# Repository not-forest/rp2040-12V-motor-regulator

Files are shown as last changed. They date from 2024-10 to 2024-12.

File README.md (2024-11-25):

# RP2040-Zero Powered 12V Motor Controller

RP2040 microcontroller handles status LEDs, an H-Bridge driver, and a rotary encoder input. RP2040's **PIO** is used to read encoder signals as a state machine, completely restraining bouncing errors from the input lines. This allows to use cheap encoders and have an amazing precision.

---

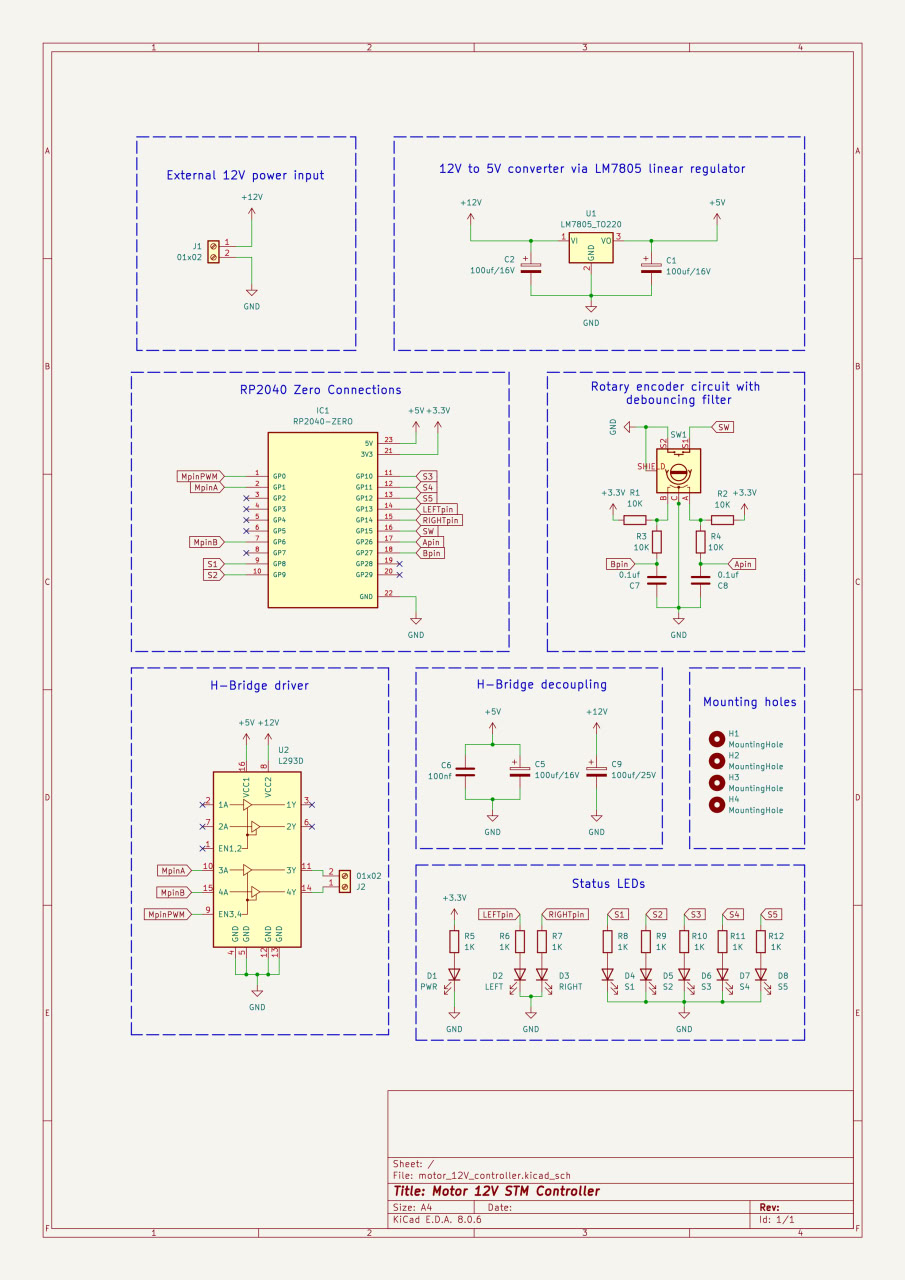
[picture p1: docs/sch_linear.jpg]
Schematic Linear

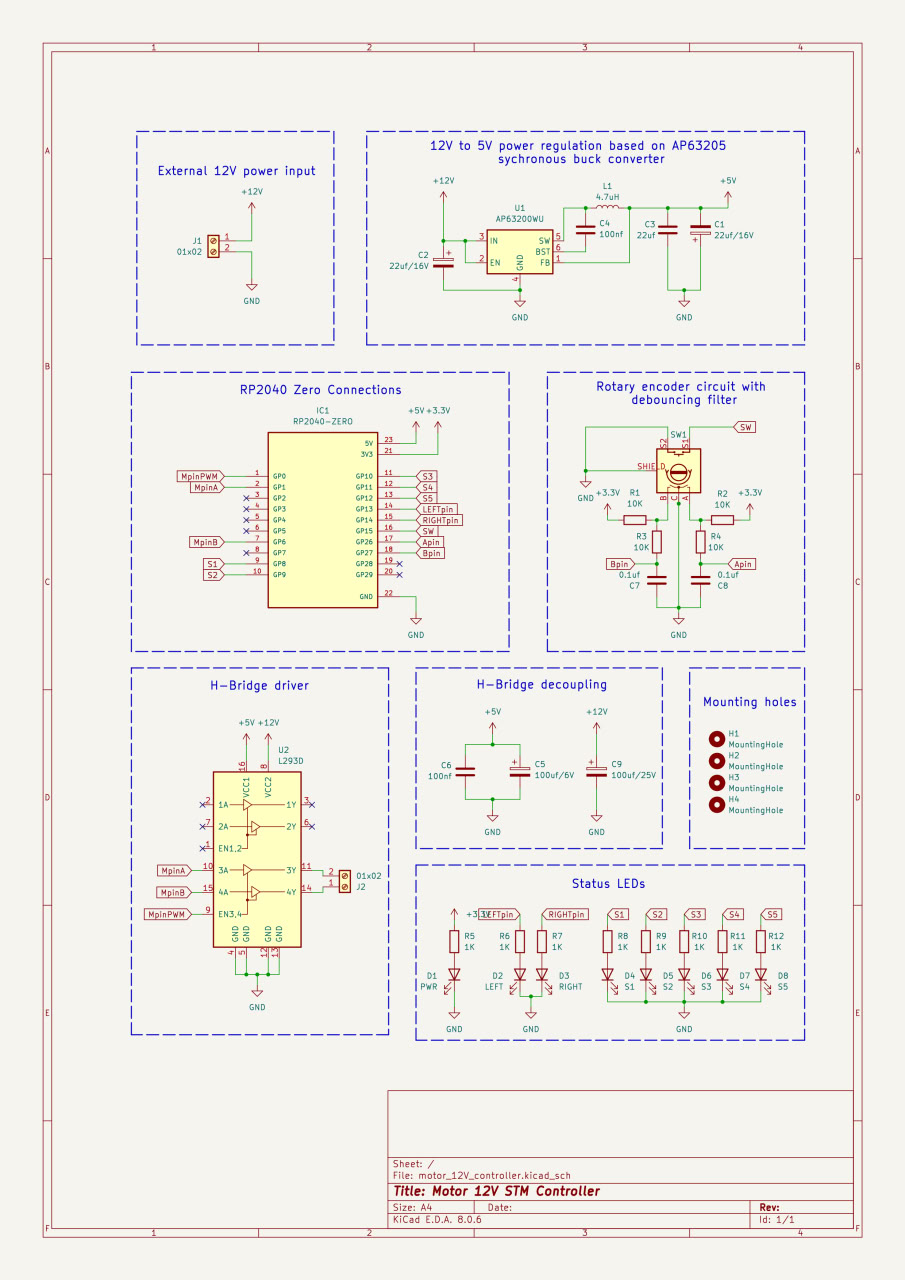
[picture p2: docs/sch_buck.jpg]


---

### PCB
- Designed in **KiCad**.
- Screw terminals 12V power input and motor output.
- Two versions include buck converter and linear regulator.

---

## Software
1. **Rotary Encoder**:
   - PIO reads encoder signals and adjusts speed.
2. **Rotary Encoder's Switch**:
   - Changes motor direction via the H-Bridge.
3. **PWM**:
   - Controls motor speed by adjusting duty cycles.
4. **Status LEDs**:
   - Show real-time speed and direction updates.

---

### Requirements
- **Rust Toolchain**: For building firmware.
- **elf2uf2-rs**: To flash the RP2040 (`cargo run` automatically searches for connected rp2040 and flashes thefirmware).
- **KiCad**: adjust PCB design.

---

Provides a reference for PIO-based rotary encoder handling in Rust.

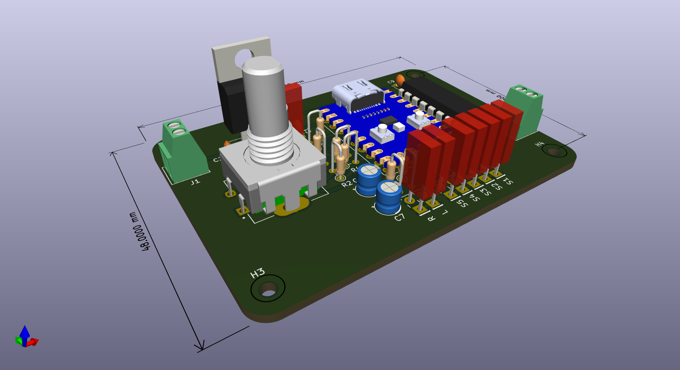
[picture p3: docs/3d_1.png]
View Linear THT

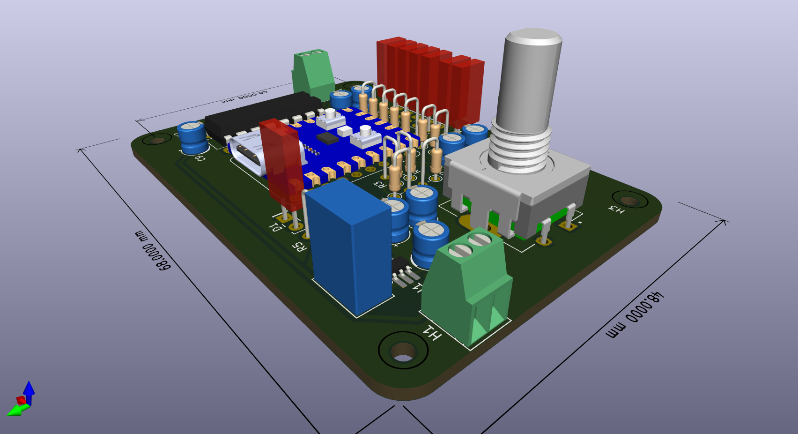
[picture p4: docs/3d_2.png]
View Buck THT

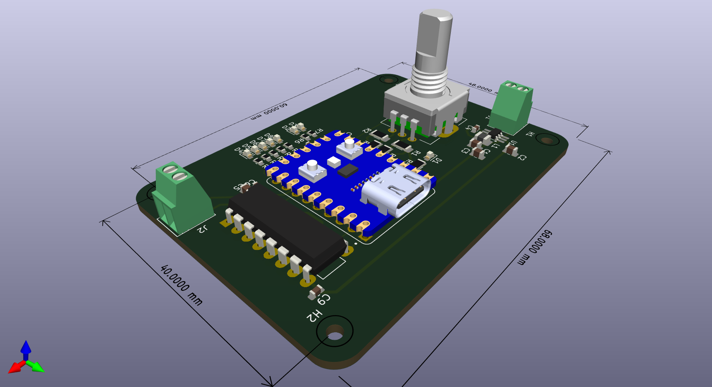
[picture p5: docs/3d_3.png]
View Buck SMD


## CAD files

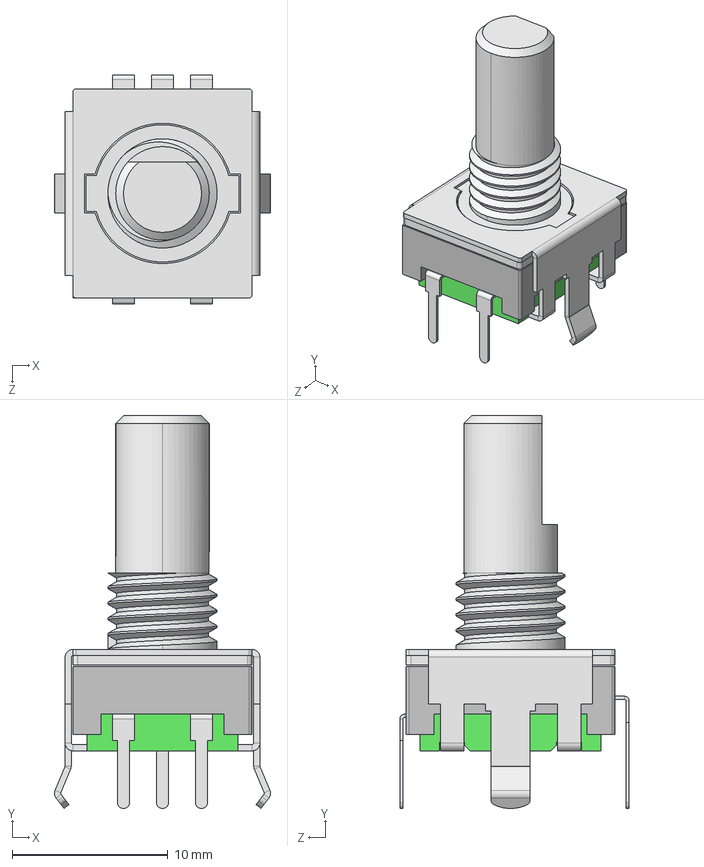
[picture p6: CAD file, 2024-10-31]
pcb/buck/symbols/PEC11R-4215F-S0024--3DModel-STEP-56544.STEP
13.9 x 25.2 x 14.7 mm

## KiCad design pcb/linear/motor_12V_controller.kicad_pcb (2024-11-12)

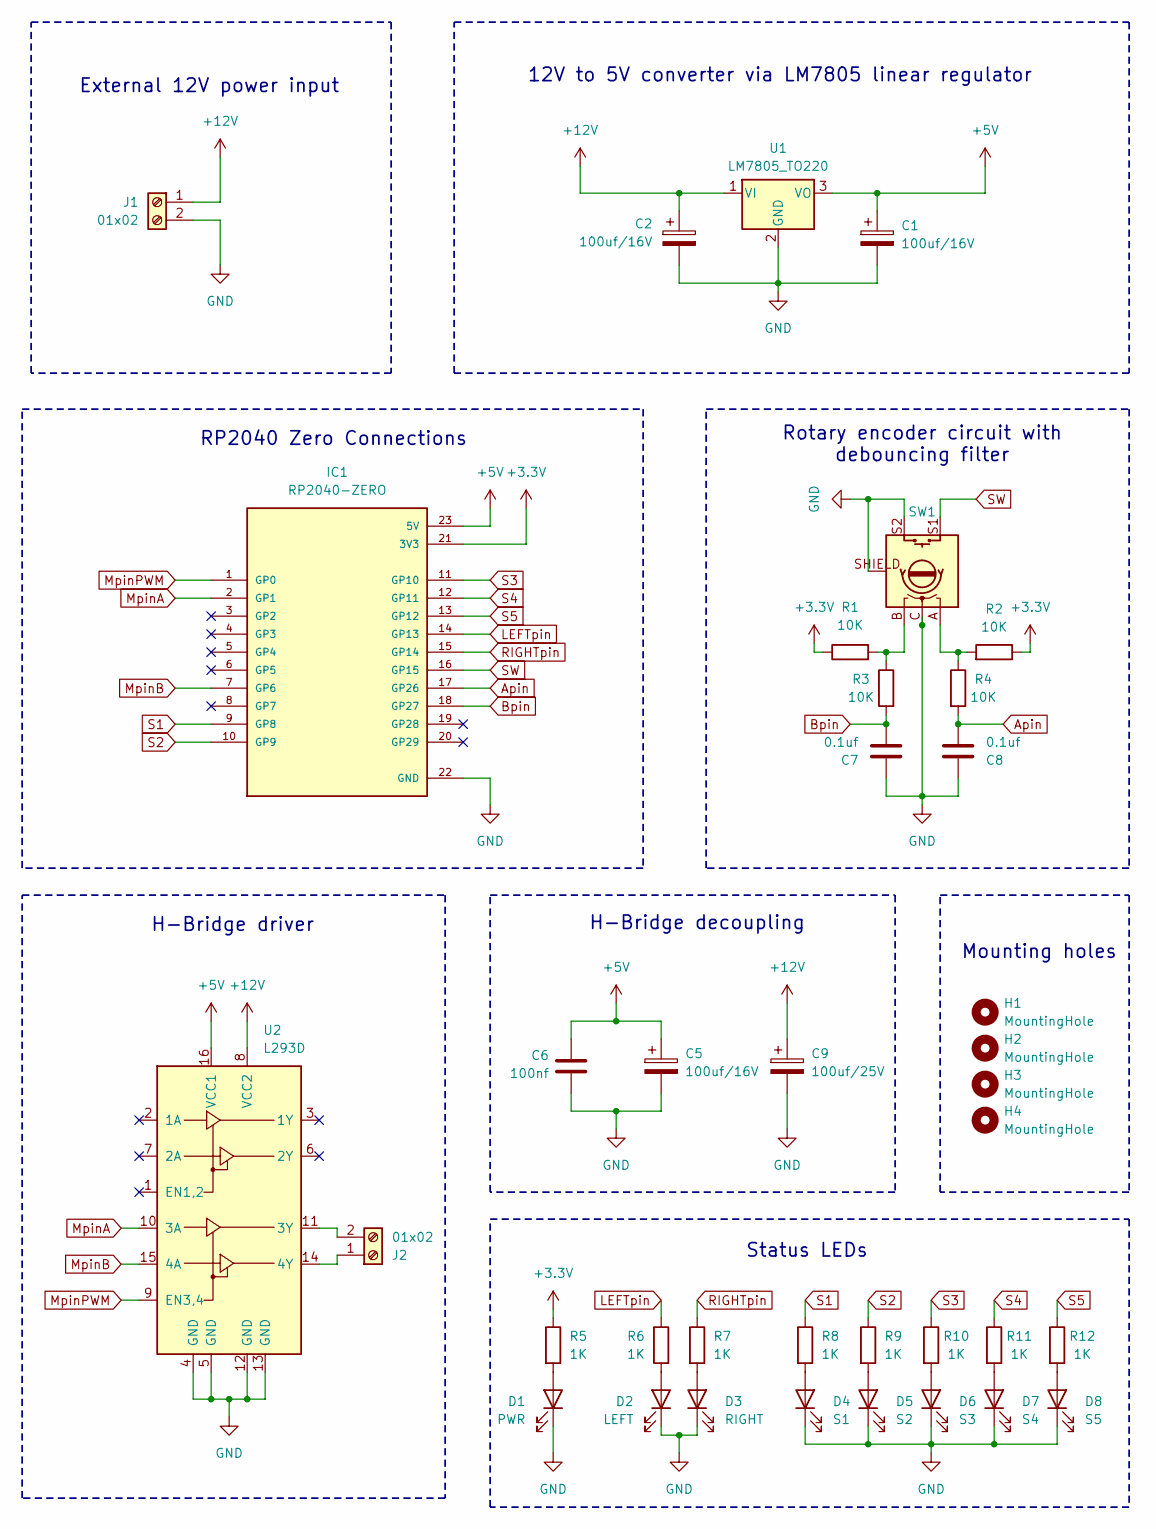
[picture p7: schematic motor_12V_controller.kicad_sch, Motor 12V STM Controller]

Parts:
C1, C2: 100uf/16V; C_Disc_D3.0mm_W1.6mm_P2.50mm
C5: 100uf/16V; C_Disc_D3.0mm_W2.0mm_P2.50mm
C6: 100nf; CP_Radial_D4.0mm_P1.50mm
C7, C8: 0.1uf; CP_Radial_D4.0mm_P1.50mm
C9: 100uf/25V; C_Disc_D3.0mm_W2.0mm_P2.50mm
D1: PWR; LED_Rectangular_W5.0mm_H2.0mm
D2: LEFT; LED_Rectangular_W5.0mm_H2.0mm
D3: RIGHT; LED_Rectangular_W5.0mm_H2.0mm
D4: S1; LED_Rectangular_W5.0mm_H2.0mm
D5: S2; LED_Rectangular_W5.0mm_H2.0mm
D6: S3; LED_Rectangular_W5.0mm_H2.0mm
D7: S4; LED_Rectangular_W5.0mm_H2.0mm
D8: S5; LED_Rectangular_W5.0mm_H2.0mm
H1, H2, H3, H4: MountingHole; MountingHole_2.2mm_M2
IC1: RP2040-ZERO; MODULE_RP2040-ZERO; PARTREV NA
J1, J2: 01x02; TerminalBlock_Xinya_XY308-2.54-2P_1x02_P2.54mm_Horizontal
R1, R2, R3, R4: 10K; R_Axial_DIN0204_L3.6mm_D1.6mm_P2.54mm_Vertical
R5, R6, R7, R8, R9, R10, R11, R12: 1K; R_Axial_DIN0204_L3.6mm_D1.6mm_P2.54mm_Vertical
SW1: XDCR_PEC11R-4215F-S0024
U1: LM7805_TO220; TO-220-3_Vertical
U2: L293D; DIP-16_W7.62mm_LongPads

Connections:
+3.3V: IC1.21 (3V3), R1.1, R2.1, R5.1
+5V: C1.1, C5.1, C6.1, IC1.23 (5V), U1.3 (VO), U2.16 (VCC1)
+12V: C2.1, C9.1, J1.1, U1.1 (VI), U2.8 (VCC2)
Apin: C8.2, IC1.17 (GP26), R4.2
Bpin: C7.2, IC1.18 (GP27), R3.2
GND: C1.2, C2.2, C5.2, C6.2, C7.1, C8.1, C9.2, D1.1 (K), D2.1 (K), D3.1 (K), D4.1 (K), D5.1 (K), D6.1 (K), D7.1 (K), D8.1 (K), IC1.22 (GND), J1.2, SW1.C, SW1.S2, SW1.SHIELD, U1.2 (GND), U2.4 (GND), U2.5 (GND), U2.12 (GND), U2.13 (GND)
LEFTpin: IC1.14 (GP13), R6.1
MpinA: IC1.2 (GP1), U2.10 (3A)
MpinB: IC1.7 (GP6), U2.15 (4A)
MpinPWM: IC1.1 (GP0), U2.9 (EN3,4)
unnamed: D1.2 (A), R5.2
unnamed: D2.2 (A), R6.2
unnamed: D3.2 (A), R7.2
unnamed: D4.2 (A), R8.2
unnamed: D5.2 (A), R9.2
unnamed: D6.2 (A), R10.2
unnamed: D7.2 (A), R11.2
unnamed: D8.2 (A), R12.2
unnamed: J2.1, U2.14 (4Y)
unnamed: J2.2, U2.11 (3Y)
unnamed: R1.2, R3.1, SW1.B
unnamed: R2.2, R4.1, SW1.A
RIGHTpin: IC1.15 (GP14), R7.1
S1: IC1.9 (GP8), R8.1
S2: IC1.10 (GP9), R9.1
S3: IC1.11 (GP10), R10.1
S4: IC1.12 (GP11), R11.1
S5: IC1.13 (GP12), R12.1
SW: IC1.16 (GP15), SW1.S1

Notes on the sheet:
Mounting holes
Rotary encoder circuit with debouncing filter
12V to 5V converter via LM7805 linear regulator
External 12V power input
RP2040 Zero Connections
H-Bridge decoupling
H-Bridge driver
Status LEDs

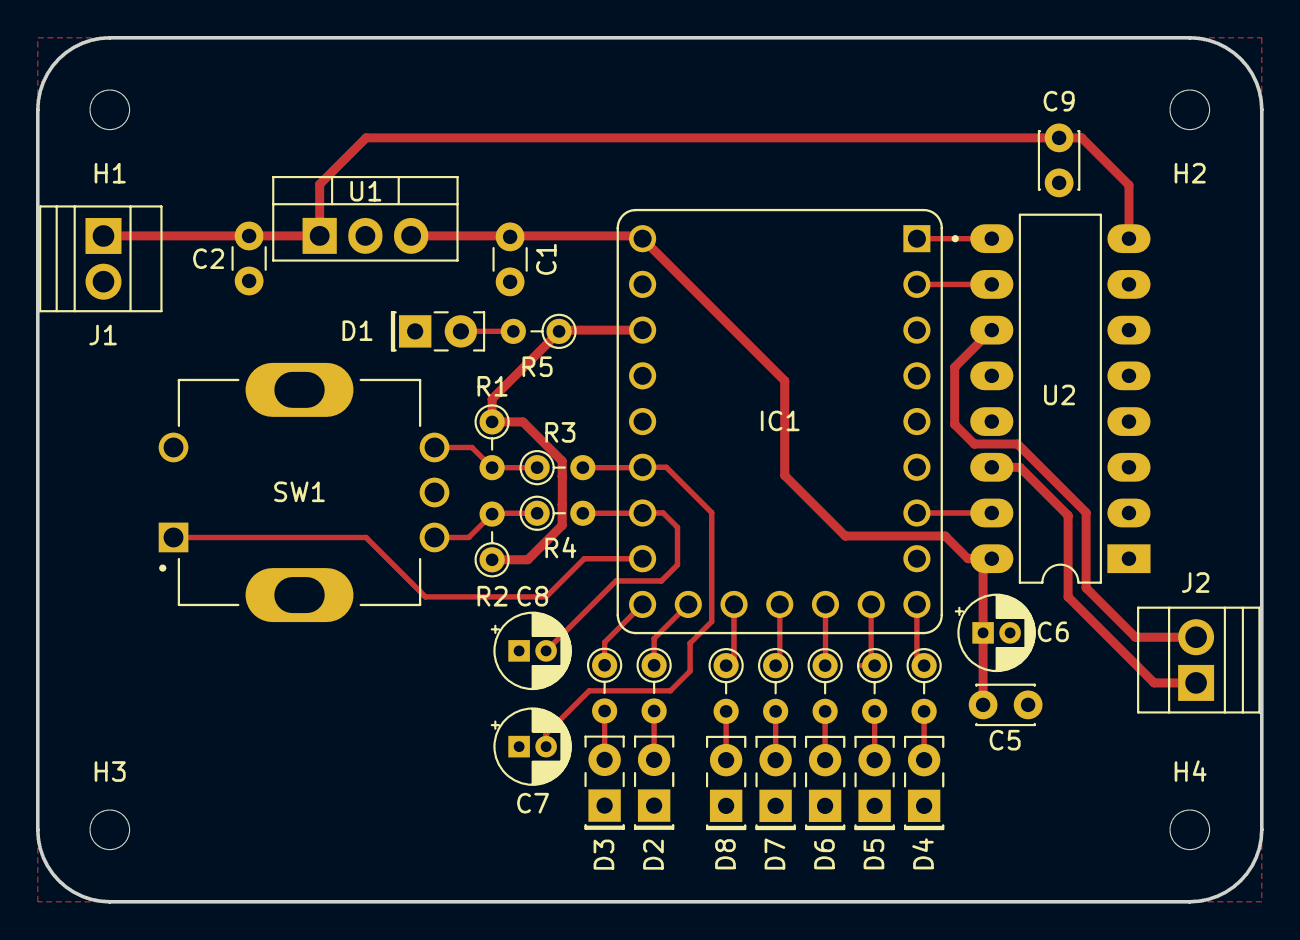
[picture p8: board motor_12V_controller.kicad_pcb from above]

Board: 2 copper layers, 68.0 x 48.0 mm, 37 parts (0 on the bottom side), 29 nets.

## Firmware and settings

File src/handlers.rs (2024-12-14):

//! Main interrupt-driver system logic.
//!
//! Mutates the current state of the system when one of three possible interrupts are encountered.
//! Adjusts status leds in the main program loop after each interrupt.

use core::cell::RefCell;
use crate::motor::MotorConfig;
use crate::{pac, cortex};

use crate::{gpios::{self, *}, pwm, xosc, pio};

use cortex::{
    interrupt::{self as int, Mutex}, 
    peripheral::NVIC,
};
use pac::interrupt;

// Motor speed added to the current spead on each encoder's rotation.
const MOTOR_GAIN_SPEED: u8 = 5;

/// Shared static motor config variable. Controls the PWM duty cycle and amount of speed leds to light.
static MOTOR_CFG: Mutex<RefCell<MotorConfig>> = Mutex::new(RefCell::new(MotorConfig::init()));

/// System setup function.
///
/// This function sets up the following:
/// - Swaps the clock source from internal ring oscillator to external XOCS.
/// - obtains the gpio port peripheral and configures it for I/Os;
/// - loads the program to the pio state machine for rotary encoder management.
/// - configures the PWM to output a 20kHz regulated signal with phase correct enabled.
/// - puts the SIO interface into a mutual exclusive reference cell.
/// - unmasks required interrupts in NVIC;
pub fn setup(dp: pac::Peripherals) {
    xosc::setup(&dp);
    gpios::setup(&dp);
    pio::setup(&dp);
    pwm::setup(&dp);

    /* Storing shared resources. */
    int::free(|cs| {
        let mut motor_cfg = MOTOR_CFG.borrow(cs).borrow_mut();

        // Moving the ownership of those interfaces to the motor config.
        motor_cfg.sio.replace(dp.SIO);
        motor_cfg.pwm.replace(dp.PWM);
        motor_cfg.pio.replace(dp.PIO0);
    });

    /* Enabling interrupts. */
    unsafe { 
        NVIC::unmask(pac::interrupt::IO_IRQ_BANK0); 
        NVIC::unmask(pac::interrupt::PIO0_IRQ_0);
        NVIC::unmask(pac::interrupt::PIO0_IRQ_1);
    };
}

/// System loop function.
///
/// Will be called after interrupt handler is done, therefore used to change
/// the state of LEDs.
pub fn main() -> ! {
    loop {
        // Changing the leds status according to the new configuration.
        int::free(|cs| {
            let mut motor_cfg = MOTOR_CFG.borrow(cs).borrow_mut();

            motor_cfg.update_leds();
        });

        cortex_m::asm::wfi();
    }
}

/// GPIO interrupt handler.
///
/// Will only be called by GPIO15 click input.
#[interrupt]
fn IO_IRQ_BANK0() {
    // IO bank is not shared between other interrupts, so this is safe. 
    let io_bank = unsafe { &*pac::IO_BANK0::ptr() };

    int::free(|cs| {
        let mut motor_cfg = MOTOR_CFG.borrow(cs).borrow_mut();

        if io_bank.proc0_ints[1].read().bits() & GPIO15_EDGE_HIGH != 0 {
            // Changing the motor direction.
            motor_cfg.change_direction();
            cortex_m::asm::delay(12000); // This will cause one ms. debounce delay
            io_bank.intr[1].write(|w| unsafe { w.bits(GPIO15_EDGE_HIGH) });
        }
    });
}

/// PIO0 IRQ0 interrupt.
///
/// Caused by PIO internal program when the rotary encoder is rotated counter clockwise.
#[interrupt]
fn PIO0_IRQ_0() {
    int::free(|cs| {
        let mut motor_cfg = MOTOR_CFG.borrow(cs).borrow_mut();
        // Decrementing the PWM duty cycle.
        motor_cfg.update_pwm(|s| s.saturating_sub(MOTOR_GAIN_SPEED));
        
        // IRQ0 must be cleared.
        motor_cfg.pio
            .as_ref()
            .map(|pio0|
                pio0.irq.write(|w| w.irq().variant(1 << 0))
            );
    });
}

/// PIO0 IRQ1 interrupt.
///
/// Caused by PIO internal program when the rotary encoder is rotated clockwise.
#[interrupt]
fn PIO0_IRQ_1() {
    int::free(|cs| {
        let mut motor_cfg = MOTOR_CFG.borrow(cs).borrow_mut();
        // Incrementing the PWM duty cycle.
        motor_cfg.update_pwm(|s| s.saturating_add(MOTOR_GAIN_SPEED));
        
        // IRQ1 must be cleared.
        motor_cfg.pio
            .as_ref()
            .map(|pio0| 
                pio0.irq.write(|w| w.irq().variant(1 << 1))
            );
    });
}

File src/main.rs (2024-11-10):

//! Main code entry area.
//!
//! RP2040 HAL libraries handles the bootloading part. The whole system logic is implemented within
//! the handlers.rs module.
#![no_std]
#![no_main]

mod gpios;
mod pwm;
mod motor;
mod xosc;
mod pio;

mod handlers;

pub use cortex_m as cortex;
pub use rp2040_hal::pac as pac;

// Panic handler.
panic_custom::define_panic!(|_| ());

/// Second stage bootloader.
#[link_section = ".boot2"]
#[used]
pub static BOOT2: [u8; 256] = rp2040_boot2::BOOT_LOADER_W25Q080;

#[cortex_m_rt::entry]
fn main() -> ! {
    let dp = pac::Peripherals::take().unwrap();
    
    // Overall system setup.
    handlers::setup(dp);
    handlers::main();
}

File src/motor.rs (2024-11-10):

//! Defines a motor configuration interface, which hold the current state of the h-bridge
//! driver system and allows to modify it.

use crate::pac::{SIO, PWM, PIO0};
use crate::gpios::*;

/// Defines the current direction of the motor.
pub enum MotorDirection{ LEFT, RIGHT }

/// Defines the current configuration of the motor.
///
/// This structure holds the current state of motor's speed and direction, but also holds the
/// ownership for SIO and PWM references. 
pub struct MotorConfig {
    speed: u8,
    dir: MotorDirection,

    pub sio: Option<SIO>,
    pub pwm: Option<PWM>,
    pub pio: Option<PIO0>,
}

use MotorDirection::*;
impl MotorConfig {
    /// Returns the initialized configuration for motor driver.
    pub const fn init() -> Self {
        Self {
            speed: u8::MIN,
            dir: MotorDirection::RIGHT,
            sio: None,
            pwm: None,
            pio: None,
        }
    }

    /// Just swaps the current direction to a different one, each time when called.
    pub fn change_direction(&mut self) {
        self.dir = match self.dir {
            LEFT => RIGHT,
            RIGHT => LEFT,
        } 
    }

    /// Updates the current PWM duty cycle based on the provided closure.
    pub fn update_pwm<F>(&mut self, f: F) where 
        F: FnOnce(u8) -> u8
    {
        self.speed = f(self.speed);
        self
            .pwm
            .as_mut()
            .map(|pwm| 
                pwm.ch[0].cc.write(|w| unsafe {
                    w.a().bits(self.speed as u16)
                })
            );
    }

    /// Updates status LEDs located on the board based on the current configuration. 
    pub fn update_leds(&mut self) {
        const MOTOR_SPEED_STEP: u8 = u8::MAX / 6;   // 6 possible states.
        const MOTOR_SPEED_LEDS: [usize; 5] = [S1, S2, S3, S4, S5];

        let mut mask: u32 = 0; 

        // Writing values on output pins according to the current direction.
        match self.dir {
            LEFT => mask |= (1 << LEFT_PIN) | (1 << MPIN_A),
            RIGHT => mask |= (1 << RIGHT_PIN) | (1 << MPIN_B),
        }
    
        // Writing values to the motor speed pins according to the current speed.
        MOTOR_SPEED_LEDS
            .into_iter()
            .take((self.speed / MOTOR_SPEED_STEP) as usize)
            .for_each(|led| mask |= 1 << (led as u32));

        self.sio
            .as_mut()
            .map(|sio| 
                sio.gpio_out.write(|w| unsafe { 
                    w.gpio_out().bits(mask) 
                })
            );
    }
}

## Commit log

2024-10-31 Added the first schematic layout and RP2040 Zero symbol file.
    [motor_12V_controller.kicad_sch]
2024-10-31 Swapped the connections to to create more compact PCB design.
    [motor_12V_controller.kicad_sch]
2024-10-31 Added more symbols and 3d models for PCB design.
    [PEC11R-4215F-S0024--3DModel-STEP-56544.STEP, PEC11R-4215F-S0024.step]
2024-10-31 Added the first PCB design layout for a single layered, SMD, ground plane solution. Some changes might appear when implementing the source code or searching for components.
    [motor_12V_controller.kicad_pcb]
2024-10-31 Configuration for flashing hardware onto the ARM M0 core in RP2040.
2024-11-02 Got rid of printing libraries.
2024-11-02 Removed the probe flashing and defmt environment constant.
2024-11-02 Added module that describes the current motor driver's configuration and a set of functions to modify it.
2024-11-02 Defines all constant GPIO IDs with names for current circuit implementation.
2024-11-02 Written the GPIO setup part. Configured output and input pins with interrupts.
2024-11-03 Fixed the pullup bug on the switch pin, which was caused due to the default pulldown defined in the reference manual. Implemented a properly working direction switching mechanism via interrupts. Now 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
    [handlers.rs]
2024-11-03 Increased the speed step for each encoder's rotation. For leds using 6 possible states to include the state where no leds are used.
2024-11-03 Added a proper interrupt handling for encoder's A and B pins.
2024-11-03 Changed the rotary encoder's circuit part to use 3.3V voltage logic, since it is connected toRP2040 pins.
    [motor_12V_controller.kicad_sch]
2024-11-03 Fixed the PCB according to new 3.3V connections.
    [motor_12V_controller.kicad_pcb]
2024-11-03 Changed the leds updating function to do it within the function itself, with provided SIO block.
2024-11-03 Added the PWM management based on the required implementation.
2024-11-04 Added one more interrupt mask for Bpin
2024-11-04 Causing two interrupts on both Apin and Bpin and progressing the state machine.
2024-11-04 The speed adjustment function implementation is now changed to a state machine of a rotary encoder. It is still not sufficient enough to prevent all bouncing problems a regular encoders have.
    [motor.rs]
2024-11-04 Added clock switching setup routine to properly output 20kHz signal from the PWM pin for quiet motor.
2024-11-06 Updated the schematic for better match of footprints for tht elements.
    [motor_12V_controller.kicad_sch]
2024-11-06 Swapped the SMD schematic to the THT one. Adjusted the AP632xx circuit according to the layout specified in the datasheet.
    [motor_12V_controller.kicad_pcb]
2024-11-06 Fixed the H-Bridge decoupling. Added additional capasitor for +12V power input.
    [motor_12V_controller.kicad_sch]
2024-11-07 Stripped the pcb and schematics into linear and buck for different 12V to 5V converters.
    [PEC11R-4215F-S0024--3DModel-STEP-56544.STEP, PEC11R-4215F-S0024.step, motor_12V_controller.kicad_pcb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]
2024-11-07 Removed items.
    [PEC11R-4215F-S0024--3DModel-STEP-56544.STEP, PEC11R-4215F-S0024.step, motor_12V_controller.kicad_pcb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]
2024-11-07 Moved the PWM setup to the it's own module.
2024-11-07 Moved the setup functions to their own modules. Using motor structure as an interface to mutate the state of the system.
2024-11-07 Now motor structure owns the SIO and PWM interfaces allowing to hide the logic behind it.
2024-11-09 Changed the symbols for THT ceramic capacitors footprint. Swapped the footprints on the PCB design
    [motor_12V_controller.kicad_pcb, motor_12V_controller.kicad_sch]
2024-11-09 Added additional RC filtering for the encoder's switch.
    [motor_12V_controller.kicad_pcb, motor_12V_controller.kicad_sch]
2024-11-10 Added new pio-rs dependency for assembling .pio assembler programs.
2024-11-10 Removed interrupts from APIN and BPIN. Now encoder is managed fully by the PIO block.
2024-11-10 State machine logic is fully reimplemented and moved for PIO to handle separately from the main core. IRQ0 and IRQ1 obtained from the PIO0 is now used to increment and decrement the PWM. Encoder is n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
2024-11-10 Added PIO setup module. It configures PIO block and one of it's state machines to run custom assembler code for managing the rotary encoder fully.
2024-11-10 Added the pio assembler code for handling the rotary encoder. Jump table is being used to handle every possible state of encoder. Counters are used for debouncing.
2024-11-12 Removed the unecessary RC filter. Purely software debouncing will be used for the switch interface.
    [motor_12V_controller.kicad_pcb, motor_12V_controller.kicad_sch]
2024-12-14 Using edge interrupt on SW pin for debouncing.
2024-12-14 Additional debouncing delay for the switch button handling. Now using edge interrupt to prevent additional jumps between the latches.
    [handlers.rs]
